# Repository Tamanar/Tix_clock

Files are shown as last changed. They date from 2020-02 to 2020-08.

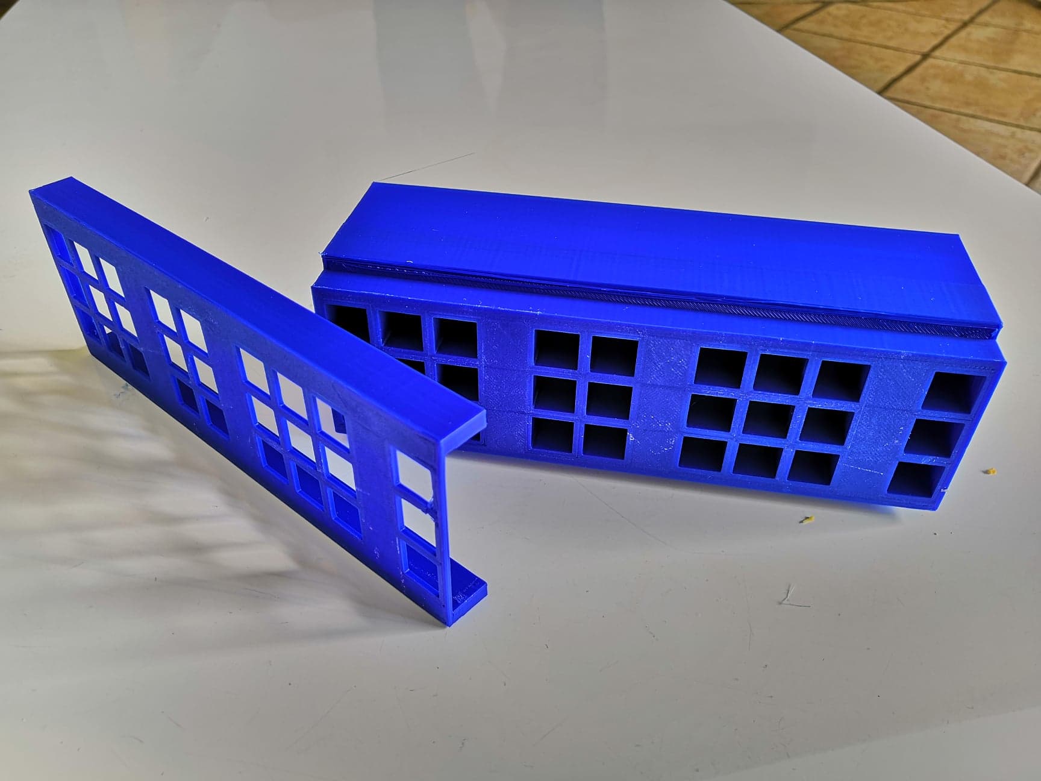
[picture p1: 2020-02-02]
3D print.jpg

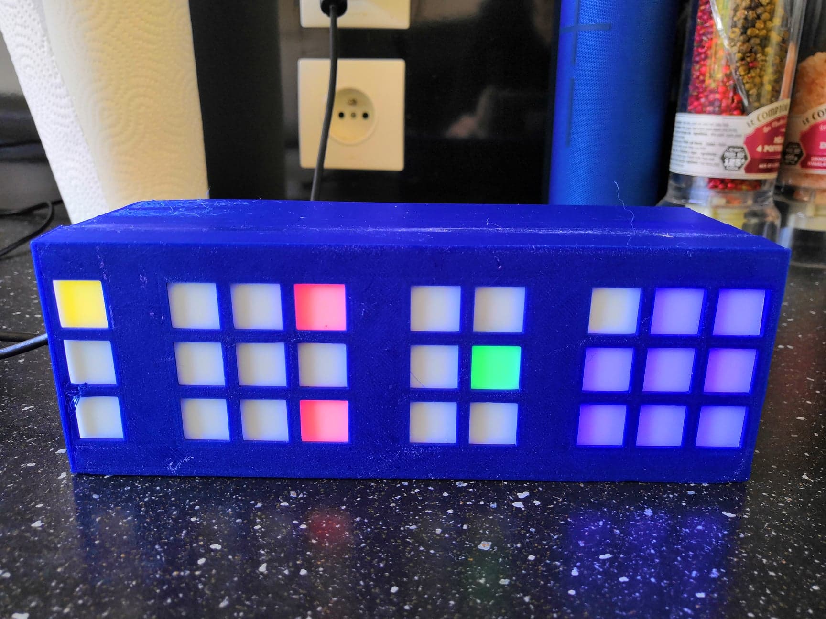
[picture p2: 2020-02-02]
3D printing working.jpg

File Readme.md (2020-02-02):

# Fabrication Tix clock

*Il existe deux versions. Une version ou le changement d'heure été/hiver s'effectue via un interrupteur et une version bluetooth où, il est possible de changer la couleur des différent pannels et le changement d'heure via une application, bluetooth electronic.*

**Étape Hardware :**
- Fabriquer/trouver votre contenant pour votre électronique (soit en bois soit tout imprimé en 3D)
- Imprimer le support pour les Leds
- Découper une planche pour coller les leds. Faire attention aux sens des leds
- Braser(souder) les leds entre elles (faite bien attention pour le fil de donnée de bien suivre les flèches)
- Relier le fil de données (pin 6 par défaut) à l'arduino
- Relier le DS3231 à l'arduino (SDA sur A4 et SCL sur A5 par défaut)

- Si Version bluetooth:
    - Brancher le module bluetooth sur le RX et le TX sur l'arduino(pensez à croiser les fils (Rx sur tx et inversment))
- Si version simple
    - Brancher l'interrupteur sur l'arduino (pin 8 par défaut) et sur le 5V
    - Penser à mettre une résistance de pull-down entre le pin 8 et la masse

**Étape Software:**

- Si version Bluetooth
    - Avec un programme tierce programmer votre recépteur bluetooth. (Ce n'est pas le but ici Cf cette [vidéo](https://www.youtube.com/watch?v=iC564i0wf0k))
    - Télécharger sur Android l'application **Bluetooth Electronics** 
    - Télécharger sur votre téléphone le fichier **tix_clock.kwl**
    - Sur l'application, en haut à gauche, sur la disquette, faîtes `load panels` et choisissez le fichier précédent.

- Télécharger [Arduino](https://www.arduino.cc/en/Main/Software)
- Aller dans croquis -> inclure une bibliothèque -> ajouter la bibliothèque zip -> choisir `DS3231.zip` et `FastLED-master.zip`    
 - Dans la boucle setup décommenter `rtc.setTime(11,47 , 00);`, mettre l'heure actuel.
- Téléverser le programme dans l'arduino pour mettre à l'heure le DS3231
- Commenter de nouveau `rtc.setTime(11,47 , 00);` 
- Téléverser de nouveau le programme. Sinon à chaque fois que l'arduino rebootera il rénitialisera le DS3231

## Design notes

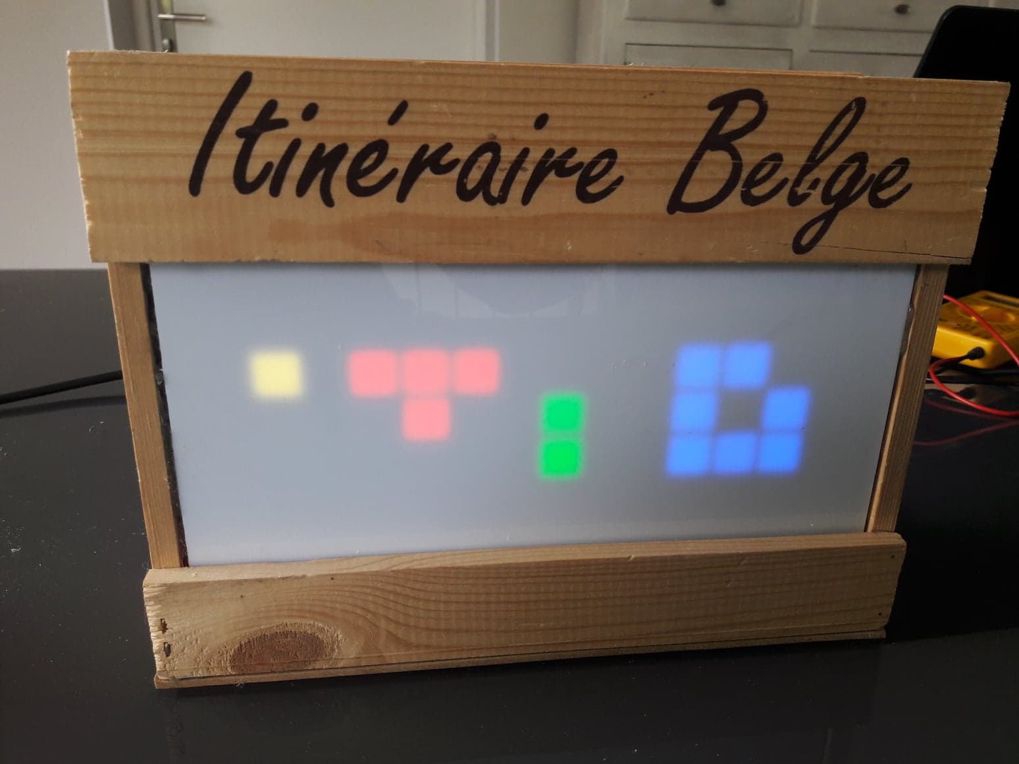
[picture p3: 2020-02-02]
Tix_clock_complete_1.jpg

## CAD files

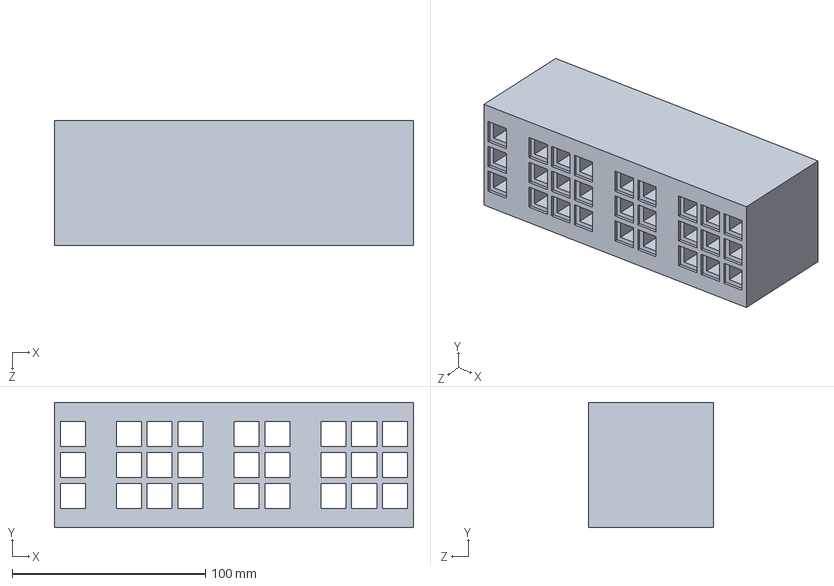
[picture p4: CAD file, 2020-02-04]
horloge-3D.sldprt
186.0 x 65.0 x 65.0 mm

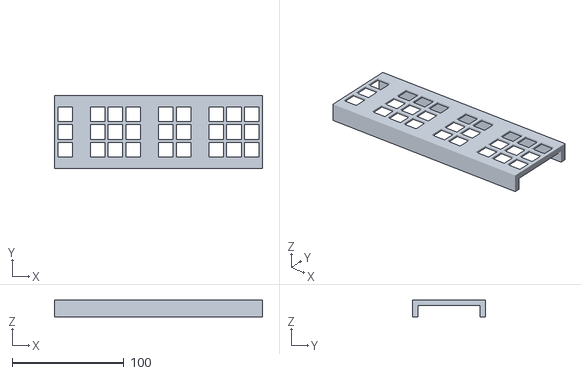
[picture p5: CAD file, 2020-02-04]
Tix_clock_TOP.STL
186.0 x 65.0 x 15.0

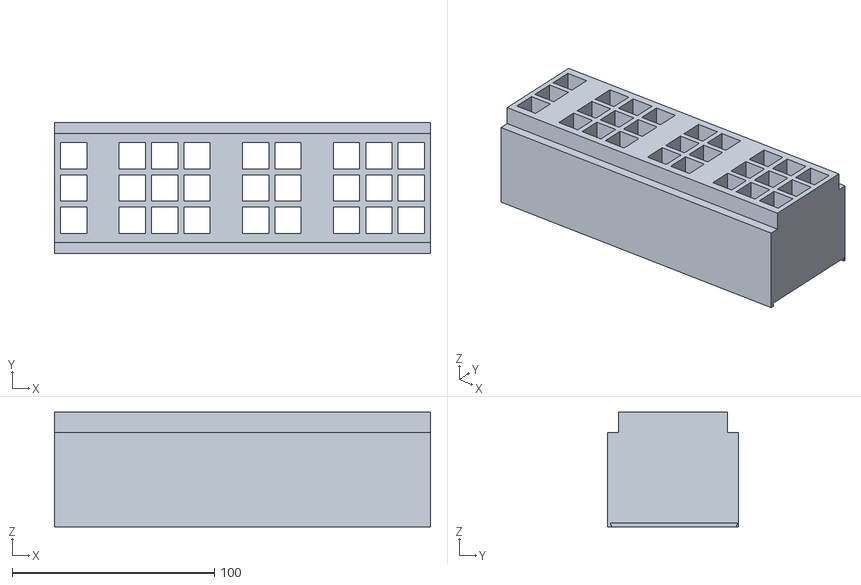
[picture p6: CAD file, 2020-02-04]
Tix_clock_bottom.STL
186.0 x 65.0 x 56.7

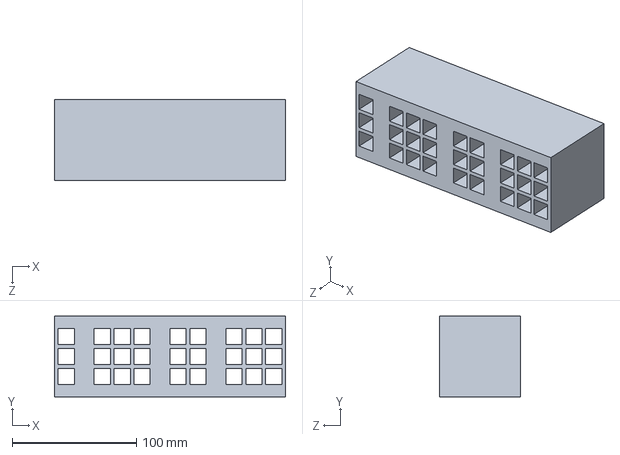
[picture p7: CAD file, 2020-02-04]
horloge-3D_sans_protection.sldprt
186.0 x 65.0 x 65.0 mm

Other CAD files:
basse_horloge.SLDPRT
haute_horloge.SLDPRT
Tix_clock_One_Piece.STL
Tix_clock_Double_Piece.STL

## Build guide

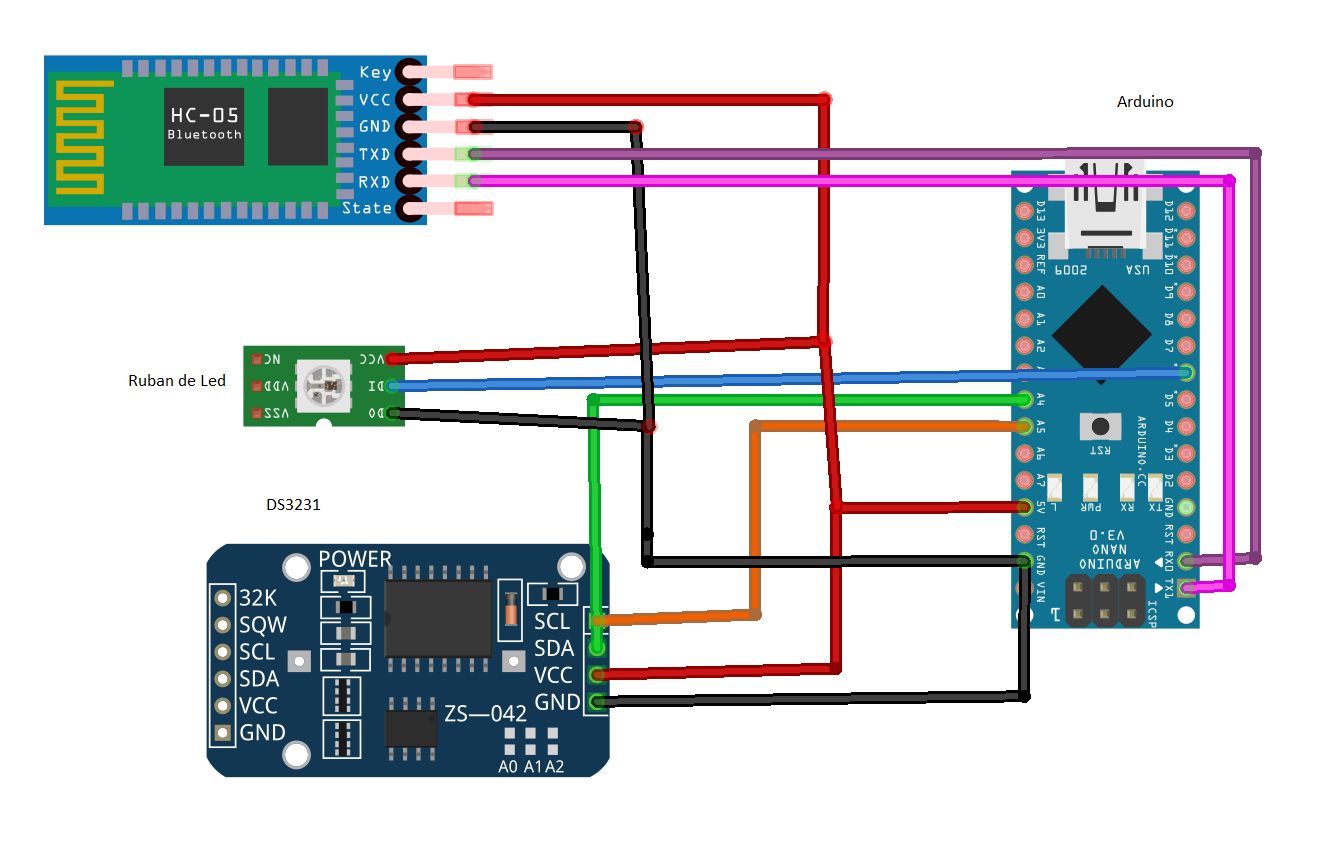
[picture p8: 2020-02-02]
Montage bluetooth.png

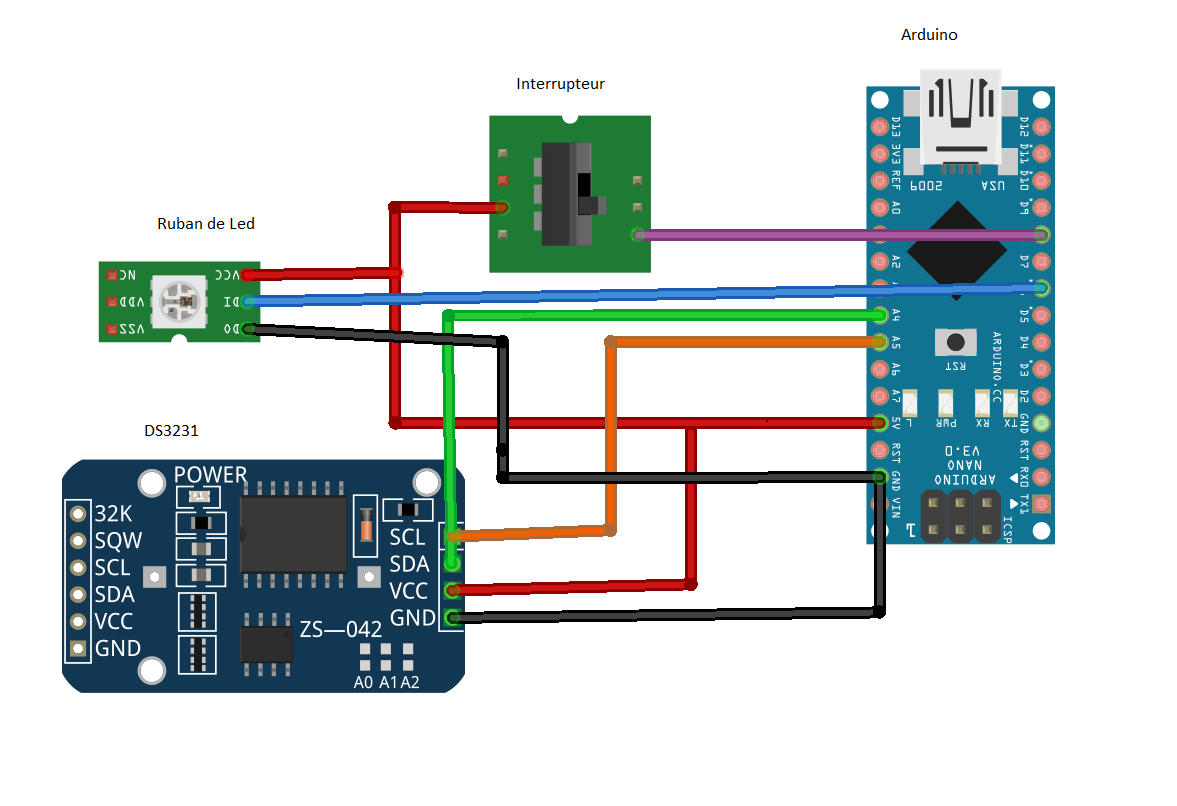
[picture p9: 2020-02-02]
Montage avec interrupteur.png

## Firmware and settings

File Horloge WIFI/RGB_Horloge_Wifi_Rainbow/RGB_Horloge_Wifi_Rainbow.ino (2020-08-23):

// DS3231_Serial_Hard
// Copyright (C)2015 Rinky-Dink Electronics, Henning Karlsen. All right reserved
// web: http://www.RinkyDinkElectronics.com/
//
// A quick demo of how to use my DS3231-library to
// retrieve time- and date-data for you to manipulate.
//
// To use the hardware I2C (TWI) interface of the Arduino you must connect
// the pins as follows:
//
// Arduino Uno/2009:
// ----------------------
// DS3231:  SDA pin   -> Arduino Analog 4 or the dedicat                                                                                                                                       ed SDA pin
//          SCL pin   -> Arduino Analog 5 or the dedicated SCL pin
//
// Arduino Leonardo:
// ----------------------
// DS3231:  SDA pin   -> Arduino Digital 2 or the dedicated SDA pin
//          SCL pin   -> Arduino Digital 3 or the dedicated SCL pin
//
// Arduino Mega:
// ----------------------
// DS3231:  SDA pin   -> Arduino Digital 20 (SDA) or the dedicated SDA pin
//          SCL pin   -> Arduino Digital 21 (SCL) or the dedicated SCL pin
//
// Arduino Due:
// ----------------------
// DS3231:  SDA pin   -> Arduino Digital 20 (SDA) or the dedicated SDA1 (Digital 70) pin
//          SCL pin   -> Arduino Digital 21 (SCL) or the dedicated SCL1 (Digital 71) pin
//
// The internal pull-up resistors will be activated when using the
// hardware I2C interfaces.
//
// You can connect the DS3231 to any available pin but if you use any
// other than what is described above the library will fall back to
// a software-based, TWI-like protocol which will require exclusive access
// to the pins used, and you will also have to use appropriate, external
// pull-up resistors on the data and clock signals.
//

#include <DS3231.h>
#include <Wire.h>
#define DS3231_I2C_ADDRESS 0x68
// Init the DS3231 using the hardware interface
DS3231  rtc(A4, A5);

// Init a Time-data structure
Time  t;

#include <SoftwareSerial.h>

SoftwareSerial SerialBTS(10, 11); // RX | TX

#include "FastLED.h"

// How many leds in your strip?
#define NUM_LEDS 27

// For led chips like Neopixels, which have a data line, ground, and power, you just
// need to define DATA_PIN.  For led chipsets that are SPI based (four wires - data, clock,
// ground, and power), like the LPD8806 define both DATA_PIN and CLOCK_PIN
#define DATA_PIN 6
#define CLOCK_PIN 13

// Define the array of leds
CRGB leds[NUM_LEDS];

//essaie avec 12:46
int dH=1;
int mH=4;
int dM=3;
int mM=6;

int leddH[]={0,0,0};
int ledmH[]={0,0,0,0,0,0,0,0,0};
int leddM[]={0,0,0,0,0,0};
int ledmM[]={0,0,0,0,0,0,0,0,0};
int randdH=-1;
int randmH=-1;
int randdM=-1;
int randmM=-1;

int lum=250;

float A=255,B=255,C=0,D=255,E=0,F=0,G=0,N=255,I=0,J=0,K=0,L=255;
int Heure=0; int Minute=0; int Seconde=0;
const char LEDRdH='A' ,LEDGdH='B',LEDBdH='C';
const char LEDRmH='D' ,LEDGmH='E',LEDBmH='F';
const char LEDRdM='G' ,LEDGdM='N',LEDBdM='I';
const char LEDRmM='J' ,LEDGmM='K',LEDBmM='L';
const char SetHeure='Q', SetMin='M',SetSec='S';
const char SetRainbow='O';
bool Rainbow=false;
int wheel=0;
int test=-1;
void setup() {
  Wire.begin();
  // put your setup code here, to run once:
  FastLED.addLeds<WS2812B, DATA_PIN, GRB>(leds, NUM_LEDS);
  
  // Setup Serial connection
  Serial.begin(115200);
  // Uncomment the next line if you are using an Arduino Leonardo
  //while (!Serial) {}
  
  // Initialize the rtc object
  rtc.begin();
  SerialBTS.begin(115200);
  
  //rtc.setTime(21,33 , 00);
  }

void loop() {
  
  
  // Read from Arduino Serial Monitor and send to HC-05
  if (Serial.available())
  SerialBTS.write(Serial.read());
  
  
  
  // Get data from the DS3231
  
  t = rtc.getTime();
  int H=t.hour;
  int M=t.min;
  
  if (H>7 and H<21)lum=1;
  
  
  else lum=5;
  dH=int(H/10);
  mH=int(H%10);
  dM=int(M/10);
  mM=int(M%10);
  
  /*
  Serial.println(dH);
  Serial.println(mH);
  Serial.println(dM);
  Serial.println(mM);
  
  if ((Q==1)) {
    rtc.setTime(H+1, t.min, t.sec);     // Set the time to 12:00:00 (24hr format); // Si le bouton a un état différent de celui enregistré et  que cet état est "haut"
    Q=-1;
    }
  else if ((Q== 0)){
    rtc.setTime(H-1, t.min, t.sec); // Si le bouton a un état différent de celui enregistré et  que cet état est "haut"
    Q=-1;
    }*/

   
    

  //------------------------------------------
  if (dM!=0){
    for (int i=1;i<=dM;i++){
      randdM=random(0,6);
      while (leddM[randdM]==1){
        randdM=random(0,6);
        if (leddM[randdM]==0)break;
        }
      leddM[randdM]= 1;
      }
    if(Rainbow){
      if (wheel <64){
        for (int i=0;i<6;i++) if (leddM[i]==1)leds[i+12].setRGB( (wheel*4)/lum,(255)/lum,0 );
        }
      else if (wheel<128){
        for (int i=0;i<6;i++) if (leddM[i]==1)leds[i+12].setRGB( (255)/lum,(255-(wheel-64)*4)/lum,0);
        }
       else if (wheel<192){
        for (int i=0;i<6;i++) if (leddM[i]==1)leds[i+12].setRGB( (255-(wheel-128)*4)/lum,0,((wheel-128)*4)/lum);
        }
      else if (wheel<=255){
        for (int i=0;i<6;i++) if (leddM[i]==1)leds[i+12].setRGB( 0,((wheel-192)*4)/lum,(255-(wheel-192)*4)/lum);
        }
      }
    else{
      for (int i=0;i<6;i++) if (leddM[i]==1)leds[i+12].setRGB( G/lum, N/lum,I/lum );
      }
    }
  //--------------------------------------------------------
  
  //------------------------------------------
  if (dH!=0){//si l'heure est à zero sa sert à rien d'allumer une led
    for (int i=0;i<dH;i++){ //je passe dans la boucle autant de fois qu'il y a de led à allumer
      randdH=random(0,3); //tire une position au hasard en fonction du nombre de position possible
      while (leddH[randdH]==1){ //tant que la position à déja été tirer je recommance
        randdH=random(0,3); //tire une position au hasard en fonction du nombre de position possible
        if (leddH[randdH]==0)break;//je pars de la boucle while si je tombe sur une position pas encore obtenue( je dois le faire sinon ça bug )
        }
      leddH[randdH]= 1; //je met un 1 à la position tiré qui est bonne
      }
    if(Rainbow){
      if (wheel <64){
        for (int i=0;i<3;i++)if (leddH[i]==1)leds[i].setRGB( ((256-wheel*4))/lum,0,(wheel*4)/lum );
        }
      else if (wheel<128){
        for (int i=0;i<3;i++)if (leddH[i]==1)leds[i].setRGB( 0,((wheel-64)*4)/lum,(255-(wheel-64)*4)/lum);
        }
      else if (wheel<192){
        for (int i=0;i<3;i++)if (leddH[i]==1)leds[i].setRGB( ((wheel-128)*4)/lum,(255)/lum,0);
        }
      else if (wheel<=255){
        for (int i=0;i<3;i++)if (leddH[i]==1)leds[i].setRGB(255/lum,(255-(wheel-192)*4)/lum,0);
        }
      }
    else{
      for (int i=0;i<3;i++)if (leddH[i]==1)leds[i].setRGB( A/lum, B/lum,C/lum); //je regarde à chaque position si la led doit etre allumé ou pas et j'indique qu'elle doit être allumé
      }
    }
  //--------------------------------------------------------
  
  //------------------------------------------
  if (mM!=0){
    for (int i=1;i<=mM;i++){
      
      randmM=random(0,8);
      
      while (ledmM[randmM]==1){
        randmM=random(0,9);
        if (ledmM[randmM]==0)break;
        }
      ledmM[randmM]= 1;
      }
    
    if(Rainbow){
      if (wheel <64){
        for (int i=0;i<9;i++)if (ledmM[i]==1)leds[i+18].setRGB( (255)/lum,255-(wheel*4)/lum,0 );
        }
      else if (wheel<128){
        for (int i=0;i<9;i++)if (ledmM[i]==1)leds[i+18].setRGB( (255-(wheel-64)*4)/lum,0,((wheel-64)*4)/lum);
        }
      else if (wheel<192){
        for (int i=0;i<9;i++)if (ledmM[i]==1)leds[i+18].setRGB(0,((wheel-128)*4)/lum,(255-(wheel-128)*4)/lum);
        }
        
      else if (wheel<=255){
        for (int i=0;i<9;i++)if (ledmM[i]==1)leds[i+18].setRGB((wheel-192)*4/lum,255/lum,0);
        }
      }
    else{
      for (int i=0;i<9;i++) {
        if (ledmM[i]==1)leds[i+18].setRGB( J/lum, K/lum,L/lum );
        }
      }
    }
  
  //--------------------------------------------------------
  
  
  
  //------------------------------------------
  if (mH!=0){
    for (int i=0;i<mH;i++){
      randmH=random(0,9);
      while (ledmH[randmH]==1){
        randmH=random(0,9);
        if (ledmH[randmH]==0)break;
        }
      ledmH[randmH]= 1;
      }
    if(Rainbow){
      if (wheel <64){
        for (int i=0;i<9;i++)if (ledmH[i]==1)leds[i+3].setRGB( 0,(wheel*4)/lum,(255-(wheel)*4)/lum);
        }
      else if (wheel<128){
        for (int i=0;i<9;i++)if (ledmH[i]==1)leds[i+3].setRGB(((wheel-64)*4)/lum,(255)/lum,0);
        }
      else if (wheel<=192){
        for (int i=0;i<9;i++)if (ledmH[i]==1)leds[i+3].setRGB( (255)/lum,(255-(wheel-128)*4)/lum,0);
        }
       else if (wheel<=255){
        for (int i=0;i<9;i++)if (ledmH[i]==1)leds[i+3].setRGB( (255-(wheel-192)*4)/lum,0,((wheel-192)*4)/lum);
        }
      }
    else{
      for (int i=0;i<9;i++)if (ledmH[i]==1)leds[i+3].setRGB( D/lum, E/lum,F/lum );
      }
    }
  //--------------------------------------------------------
  
  
  FastLED.show();//toute les led qui ont été indiqué comme étant allumé, je les allume
  
  for (int x=0; x < 10000; x++) {     // Wait for 1 second
    delay(1);
    bluetooth();
     
    
    
    }
  
  
  for(int dot = 0; dot < NUM_LEDS; dot++)leds[dot] = CRGB::Black; //j'indique que toute les leds doivent être éteinte
  FastLED.show();//je les éteins
  
  
  //-----------------
  for (int i=0;i<=3;i++)leddH[i]=0; //je réinitialise mes listes
  //-------------------
  
  //-----------------
  for (int i=0;i<=9;i++)ledmH[i]=0;
  //-------------------
  
  //-----------------
  for (int i=0;i<=6;i++)leddM[i]=0;
  //-------------------
  
  //-----------------
  for (int i=0;i<=9;i++) {
    ledmM[i]=0;
    }
  //-------------------

  if (wheel>255){
      wheel=0;
      }
    else{
      
      wheel++;
      }

  }

void bluetooth()
{
  
  // Read from HC-05 and send it to Arduino Serial Monitor
  if (SerialBTS.available())
  {
    
    char couleur=SerialBTS.read();
    Serial.println("couleur:");
    Serial.print(couleur);
    switch (couleur)
    {
      case LEDRdH:
      {
       Rainbow=false; 
        char BUFFER[SerialBTS.available()];
        String data="";
        while(SerialBTS.available())
        {
          delay(1);
          data+=char(SerialBTS.read());
          }
        A=float(data.toInt());
        Serial.println("A");
        Serial.print(A);
        
        break;
        }
      case LEDGdH:
      {
        char BUFFER[SerialBTS.available()];
        String data="";
        while(SerialBTS.available())
        {
          delay(1);
          data+=char(SerialBTS.read());
          }
        B=float(data.toInt());
        Rainbow=false; 
        break;
        }
      case LEDBdH:
      {
        char BUFFER[SerialBTS.available()];
        String data="";
        while(SerialBTS.available())
        {
          delay(1);
          data+=char(SerialBTS.read());
          }
        C=float(data.toInt());
        Rainbow=false; 
        break;
        }
      case LEDRmH:
      {
        char BUFFER[SerialBTS.available()];
        String data="";
        while(SerialBTS.available())
        {
          delay(1);
          data+=char(SerialBTS.read());
          }
        D=float(data.toInt());
        Rainbow=false; 
        break;
        }
      case LEDGmH:
      {
        char BUFFER[SerialBTS.available()];
        String data="";
        while(SerialBTS.available())
        {
          delay(1);
          data+=char(SerialBTS.read());
          }
        E=float(data.toInt());
        Rainbow=false; 
        break;
        }
      case LEDBmH:
      {
        char BUFFER[SerialBTS.available()];
        String data="";
        while(SerialBTS.available())
        {
          delay(1);
          data+=char(SerialBTS.read());
          }
        F=float(data.toInt());
        Rainbow=false; 
        break;
        }
      case LEDRdM:
      {
        char BUFFER[SerialBTS.available()];
        String data="";
        while(SerialBTS.available())
        {
          delay(1);
          data+=char(SerialBTS.read());
          }
        G=float(data.toInt());
        Rainbow=false; 
        break;
        }
      case LEDGdM:
      {
        char BUFFER[SerialBTS.available()];
        String data="";
        while(SerialBTS.available())
        {
          delay(1);
          data+=char(SerialBTS.read());
          }
        Rainbow=false; 
        N=float(data.toInt());
        
        break;
        }
      case LEDBdM:
      {
        char BUFFER[SerialBTS.available()];
        String data="";
        while(SerialBTS.available())
        {
          delay(1);
          data+=char(SerialBTS.read());
          }
        I=float(data.toInt());
        Rainbow=false; 
        break;
        }
      case LEDRmM:
      {
        char BUFFER[SerialBTS.available()];
        String data="";
        while(SerialBTS.available())
        {
          delay(1);
          data+=char(SerialBTS.read());
          }
        J=float(data.toInt());
        Rainbow=false; 
        break;
        }
      case LEDGmM:
      {
        char BUFFER[SerialBTS.available()];
        String data="";
        while(SerialBTS.available())
        {
          delay(1);
          data+=char(SerialBTS.read());
          }
        K=float(data.toInt());
        Rainbow=false; 
        break;
        }
      case LEDBmM:
      {
        char BUFFER[SerialBTS.available()];
        String data="";
        while(SerialBTS.available())
        {
          delay(1);
          data+=char(SerialBTS.read());
          }
        L=float(data.toInt());
        Rainbow=false; 
        break;
        }
      case SetHeure:
      {
        t = rtc.getTime();
        
        int M=t.min;
        int S=t.sec;
        char BUFFER[SerialBTS.available()];
        String data="";
        while(SerialBTS.available())
        {
          delay(1);
          data+=char(SerialBTS.read());
          }
        Heure=float(data.toInt());
        
        rtc.setTime(Heure,M,S);
        
        break;
        }
      case SetMin:
      {
        t = rtc.getTime();
        int H=t.hour;
        
        int S=t.sec;
        char BUFFER[SerialBTS.available()];
        String data="";
        while(SerialBTS.available())
        {
          delay(1);
          data+=char(SerialBTS.read());
          }
        Minute=float(data.toInt());
        
        rtc.setTime(H,Minute,S);
        
        break;
        }
      case SetSec:
      {
        t = rtc.getTime();
        int H=t.hour;
        int M=t.min;
        
        char BUFFER[SerialBTS.available()];
        String data="";
        while(SerialBTS.available())
        {
          delay(1);
          data+=char(SerialBTS.read());
          }
        Seconde=float(data.toInt());
        
        rtc.setTime(H,M,Seconde);
        
        break;
        }
        case SetRainbow:
      {

        Rainbow=true;
          
        }
      }
    
    }
  
  }

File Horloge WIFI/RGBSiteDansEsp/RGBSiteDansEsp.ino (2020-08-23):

/*********
  Rui Santos
  Complete project details at http://randomnerdtutorials.com  
*********/

//Load Wi-Fi library

#include <ESP8266WiFi.h>
#include <SoftwareSerial.h>
// Replace with your network credentials
const char* ssid     = "Freebox-5C9A25";
const char* password = "viebas-plasmari?3-occultati!-incogitans";
SoftwareSerial ESPserial(3, 1); // RX | TX
// Set web server port number to 80
WiFiServer server(80);

// Decode HTTP GET value
String redString = "0";
String greenString = "0";
String blueString = "0";
String PanneauString = "0";
int r;
int g;
int b;
int pos1 = 0;
int pos2 = 0;
int pos3 = 0;
int pos4 = 0;
int pos5= 0;
// Variable to store the HTTP req  uest
String header;

// Current time
unsigned long currentTime = millis();
// Previous time
unsigned long previousTime = 0; 
// Define timeout time in milliseconds (example: 2000ms = 2s)
const long timeoutTime = 2000;

void setup() {
  Serial.begin(115200);
  // Start the software serial for communication with the ESP8266
   /* ESPserial.begin(115200);  
    
    ESPserial.write("");
    ESPserial.write("Remember to to set Both NL & CR in the serial monitor.");
    ESPserial.write("Ready");
    ESPserial.write("");   */
  
  // Connect to Wi-Fi network with SSID and password
  Serial.print("Connecting to ");
  Serial.println(ssid);
  WiFi.begin(ssid, password);
  while (WiFi.status() != WL_CONNECTED) {
    delay(500);
    Serial.print(".");
  }
  // Print local IP address and start web server
  Serial.println("");
  Serial.println("WiFi connected.");
  Serial.println("IP address: ");
  Serial.println(WiFi.localIP());
  server.begin();
}

void loop(){
  /*Serial.print("A");
  Serial.print("255");
  Serial.print("\n");
  delay(1000);*/
  WiFiClient client = server.available();   // Listen for incoming clients

  if (client) {                             // If a new client connects,
    currentTime = millis();
    previousTime = currentTime;
   // Serial.println("New Client.");          // print a message out in the serial port
    String currentLine = "";                // make a String to hold incoming data from the client
    while (client.connected() && currentTime - previousTime <= timeoutTime) {            // loop while the client's connected
      currentTime = millis();
      if (client.available()) {             // if there's bytes to read from the client,
        char c = client.read();             // read a byte, then
     //   Serial.write(c);                    // print it out the serial monitor
        header += c;
        if (c == '\n') {                    // if the byte is a newline character
          // if the current line is blank, you got two newline characters in a row.
          // that's the end of the client HTTP request, so send a response:
          if (currentLine.length() == 0) {
            // HTTP headers always start with a response code (e.g. HTTP/1.1 200 OK)
            // and a content-type so the client knows what's coming, then a blank line:
            client.println("HTTP/1.1 200 OK");
            client.println("Content-type:text/html");
            client.println("Connection: close");
            client.println();
                   
            // Display the HTML web page
            client.println("<!DOCTYPE html><html>");
            client.println("<head><meta name=\"viewport\" content=\"width=device-width, initial-scale=1\">");
            client.println("<link rel=\"icon\" href=\"data:,\">");
            client.println("<link rel=\"stylesheet\" href=\"https://stackpath.bootstrapcdn.com/bootstrap/4.3.1/css/bootstrap.min.css\">");
            client.println("<script src=\"https://cdnjs.cloudflare.com/ajax/libs/jscolor/2.0.4/jscolor.min.js\"></script>");
            client.println("</head><body><div class=\"container\"><div class=\"row\"><h1>Panneau 1</h1></div>");
            client.println("<a class=\"btn btn-primary btn-lg\" href=\"#\" id=\"change_color1\" role=\"button\">Change Color</a> ");
            client.println("<input class=\"jscolor {onFineChange:'update(this)'}\" id=\"P1\"></div>");
            client.println("<div class=\"container\"><div class=\"row\"><h1>Panneau 2</h1></div><a class=\"btn btn-primary btn-lg\" href=\"\" id=\"change_color2\" role=\"button\">Change Color</a><input class=\"jscolor {onFineChange:'update(this)'}\" id=\"P2\"></div>");
            client.println("<div class=\"container\"><div class=\"row\"><h1>Panneau 3</h1></div><a class=\"btn btn-primary btn-lg\" href=\"\" id=\"change_color3\" role=\"button\">Change Color</a><input class=\"jscolor {onFineChange:'update(this)'}\" id=\"P3\"></div>");
            client.println("<div class=\"container\"><div class=\"row\"><h1>Panneau 4</h1></div><a class=\"btn btn-primary btn-lg\" href=\"\" id=\"change_color4\" role=\"button\">Change Color</a><input class=\"jscolor {onFineChange:'update(this)'}\" id=\"P4\"></div>");
            client.println("<div id=\"buttons\"><a  href=\"\" id=\"Horloge\" role=\"button\"><button onclick=sendTime()>SetClock</button> </a></div>");
            client.println("<div id=\"buttons\"><a  href=\"\" id=\"Rainbow\" role=\"button\"><button onclick=rainbow()>Rainbow</button> </a></div>");
            client.println("<script>function update(picker) {document.getElementById(picker.targetElement.id).innerHTML = Math.round(picker.rgb[0]) + ', ' +  Math.round(picker.rgb[1]) + ', ' + Math.round(picker.rgb[2]);document.getElementById(\"change_color\"+picker.targetElement.id.slice(-1)).href=\"?r\" + Math.round(picker.rgb[0]) + \"g\" +  Math.round(picker.rgb[1]) + \"b\" + Math.round(picker.rgb[2]) +picker.targetElement.id+ \"&\";}");          // The HTTP response ends with another blank line
            client.println("function checkTime(i) {return (i < 10) ? \"0\" + i : i;}function sendTime() {var today = new Date();h = checkTime(today.getHours());min = checkTime(today.getMinutes());s = checkTime(today.getSeconds());document.getElementById(\"Horloge\").href=\"?r\"+h+\"g\"+min+\"b\"+s+\"P5&\";console.log(\"T\"+h+min+s);}");
            client.println("function rainbow(){document.getElementById(\"Rainbow\").href=\"?r1g1b1P6&\";}</script>");
            client.println();
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

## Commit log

2020-02-02 Add arduino files
2020-02-04 add stl files
    [Tix_clock_Double_Piece.STL, Tix_clock_One_Piece.STL, Tix_clock_TOP.STL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]
